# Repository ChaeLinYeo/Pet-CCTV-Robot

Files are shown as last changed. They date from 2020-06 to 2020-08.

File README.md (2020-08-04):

# Pet-CCTV-Robot
펫 자동 감지 CCTV
## Overview
  직장인들의 외출에 펫을 감시하기 위한 펫 CCTV, 하지만 기존 펫 CCTV는 사용자가 앱으로 직접 스트리밍 영상을 보면서 반려동물의 상황을 파악 해야하기 때문에 용무가 있어 외출을 한 사용자들에게는 스트리밍 영상을 통한 감시를 할 수 없는 상황이 대부분이다. 또한, 터치를 통해 구동되는 가전제품들이 증가함으로 반려동물의 사고 또한 빈번히 발생한다. 예로 반려동물 주인이 외출시 반려동물이 인덕션, 하이라이트 전자레인지 등을 건드려서 화재가 발생했다는 사건이 급증했다. ([화재사건기사내용](https://www.hankyung.com/life/article/201912041776Y)) 우리는 이에대해 기존의 제품이 구매자의 목적을 완벽하게 해소시켜주지 못한다는 점과 현재 사고들의 원인을 파악하여 사용자가 위험구역을 지정하고, 반려동물의 위치를 자동적으로 파악하여 기존 펫 CCTV의 부족한 점을 보완하고자한다.
 
## 세부 기능
- 사용자가 직접 본 기기 카메라에서 송출하는 화면을 통해 전면, 좌측, 우측 방향에 반려동물이 접근하면 안되는 구역을 설정을 할 수 있다.
- 본 기기는 인공지능을 통해 전면, 좌측, 우측 방향으로 반려동물의 위치를 파악한다.
- 반려동물이 사용자가 지정한 접근 금지 구역에 위치했을 때 기기는 음성을 송출하여 반려동물에게 제지를 하고, 사용자의 앱에 알림을 울린다. ([소리를 통해 반려동물을 제지할 수 있을까?](https://youtu.be/sFJ1QNv7OGw?t=42))

## 순차적 동작 개념 설명
1.	카메라에서 송출하고 있는 영상이 터치 스크린에 출력이 되고, 모터를 통해 움직이는 카메라의 각도(0도, 90도, 180도)별로 원하는 위험구역을 스크린에 터치한다.
2.	위험 구역 설정을 마무리하면, 카메라에서 촬영되고 있는 영상을 앱에 실시간으로 전송한다.
3.	5초 간격으로 모터를 돌려 카메라의 위치를 바꾼다. (이때 해당 카메라 각도로 설정한 위험구역을 불러온다.)
4.	고양이 / 강아지를 탐지한다.
5.	탐지한 고양이/ 강아지의 위치가 사용자가 설정한 위험구역 내에 위치할 경우 스피커로 음성 송출 및 사용자 앱에 알람을 송신한다.

## 사용재료
  라즈베리 파이3B+, 라즈베리 파이4, 라즈베리파이 카메라 모듈, USB허브, 서보모터, 마이크로 SD카드 32G, SD카드 리더기, 라즈베리파이 공식7인치 터치스크린

## 모델링
초기 모델 시안은 다음과 같다. 심미성 및 내부 하드웨어 위치를 고려하여 1번 구조를 택했으며, 이후에 하드웨어 크기를 고려하고, 3d 프린팅하기 쉬운 구조로 변형시켰다.
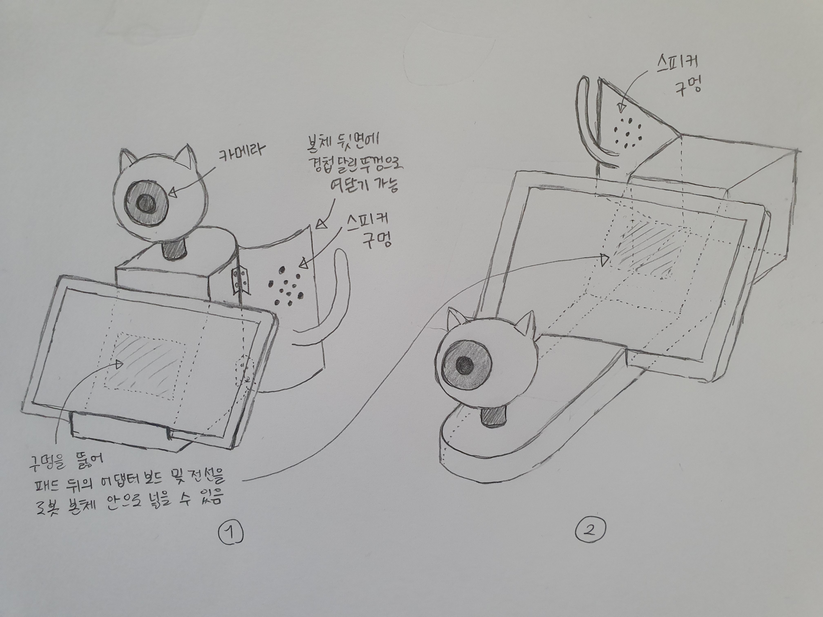
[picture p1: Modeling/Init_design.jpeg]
초기 시안

모델은 STL 파일로 첨부한다. 3D프린팅 편의를 위해 파트가 다음과 같이 분할되어 있다. 
```
.
├── cat_body_width_left.STL
├── cat_body_width_right.STL
├── real_cat_head_back.STL
├── real_cat_head_front.STL
└── real_cat_head_middle.STL
```
위의 파트들을 모두 합쳐 에셈블을 만들면 다음과 같다.
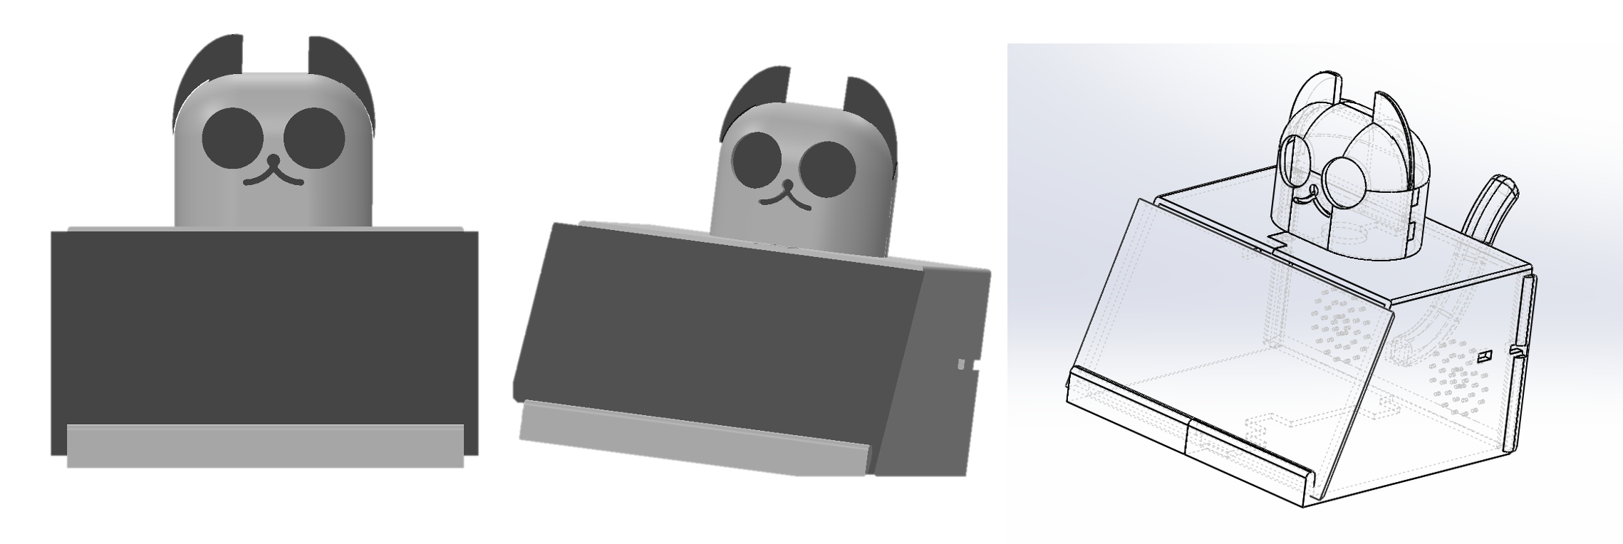
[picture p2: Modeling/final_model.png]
최종 모델


## 하드웨어 세부 구성
```
.
├── Google Edge TPU coprocessor : 인공지능 영상처리 가속화
├── raspberry pi 3 B+: 사용자에게 영상을 스트리밍 해줄 보드 
├── raspberry pi 4: 애완동물을 인식하여 위험구역을 탐지할 보드
├── arduino UNO: 모터를 제어할 보드
├── HS-311 servo motor: 카메라를 돌려줄 모터
├── SONY pi camera x 2: 카메라(하나는 애완동물 인식, 하나는 스트리밍용)
├── raspberry pi touch screen 7 inch: 사용자가 상호작용할 터치디스플레이
└── USB port speaker: 음성을 출력할 스피커
```

## 반려동물 감지 (detection)
파이카메라로 받은 영상을 Tensorflow-Lite와 OpenCV, Google의  sample TFLite model를 이용하여 고양이, 강아지, 새 등의 애완동물을 인공지능으로 학습하여 인식 가능하게 만들었다. 파이카메라로 영상을 받으면, 처음에 터치스크린을 터치하여 화면 상의 위험 구역을 선정한다. 그러면 화면 상에 고양이, 강아지 등 반려동물이 보이면 인공지능이 인식을 하고, 사용자가 선정한 위험 구역 범위에 인식된 반려동물의 좌표값이 들어오면 “Cat/Dog is danger!”라는 문구를 띄운다. 영상처리에서는 FPS를 개선하기 위해 TPU Accelerator를 사용하였으며, raspberry pi 3 B 에서 raspberry pi 4로 새로 교체하여 기존의 파이카메라로 영상처리를 할때 약 1~2 FPS였던 것을 약 30~40 FPS정도까지 끌어올려 부드러운 영상이 나오도록 했다. 
파일 실행 방법은 다음과 같다.
```
source tflite1-env/bin/activate
python3 TFLite_detection_webcam.py --modeldir=Sample_TFLite_model --edgetpu
```
## 애플리케이션
앱으로도 카메라의 영상이 스트리밍 될 수 있도록 하기 위해 UV4L을 사용하여 웹에서 영상이 스트리밍 될 수 있도록 하고, 안드로이드 스튜디오에서 웹에서 스트리밍되는 영상을 WebView를 통해 볼 수 있도록 했다. 스트리밍 하는 영상의 width, height, brightness, contrast, saturation, rgb balance, sharpness, rotate, jpeg quality, frame rate, horizontal mirror, vertical mirror, video denoise, image stabilization 등등 다양한 설정값을 변경하여 영상 스트리밍을 앱으로 받아볼 수 있다. 라즈베리 파이에서 인공지능으로 고양이, 강아지를 인식하여 사용자가 지정한 위험구역에 들어오면 앱으로 푸쉬알람을 보낸다. 사용자가 이름과 email 정보를 입력하면 반려동물이 위험구역에 접근했을 때 앱으로 알림이 가는 서비스를 구독할 수 있다. 구독자의 정보는 파이어베이스 데이터베이스에 실시간으로 반영되고, 구독 해지 시 자동으로 데이터베이스에서 정보를 삭제한다. 파이어베이스에서 사용자들의 정보와 사용량, 동시 연결 수, 클라우드 메시징(푸쉬알람)이 사용자에게 몇번 전송되고, 수신되고, 노출되고, 열렸는지를 실시간으로 모니터링할 수 있다. 또한 여러 대의 스마트폰 디바이스에서 실시간 스트리밍을 볼 수 있고, 푸쉬알람을 받을 수 있다.

## 시연 영상
Video Label (https://youtu.be/2APS1OUAQUU)

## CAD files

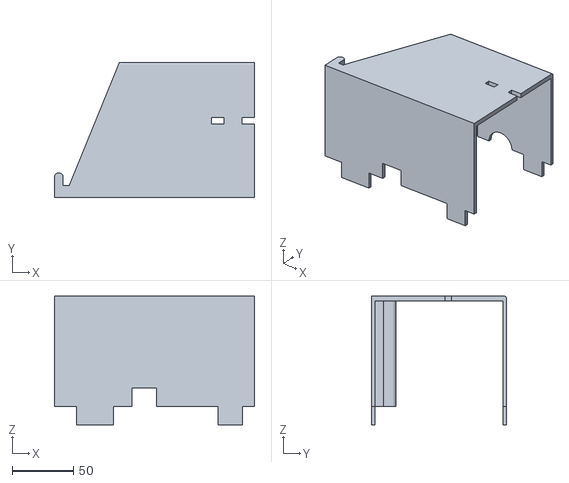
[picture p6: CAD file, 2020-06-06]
Modeling/cat_body_width_right.STL
162.8 x 110.0 x 105.0

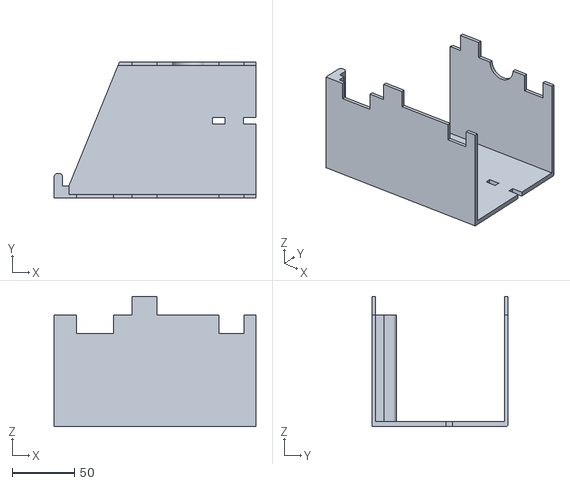
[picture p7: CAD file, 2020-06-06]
Modeling/cat_body_width_left.STL
162.8 x 110.0 x 105.0

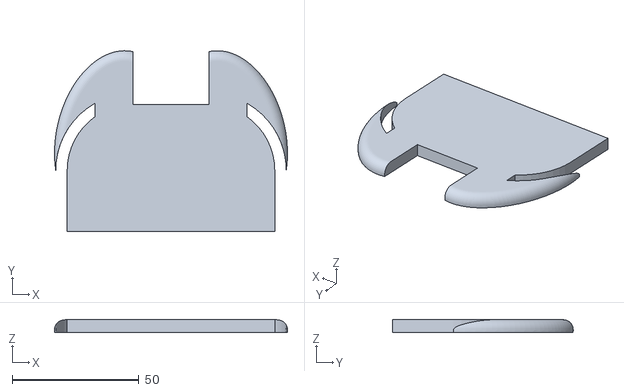
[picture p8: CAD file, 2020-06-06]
Modeling/real_cat_head_middle.STL
92.0 x 71.3 x 5.00

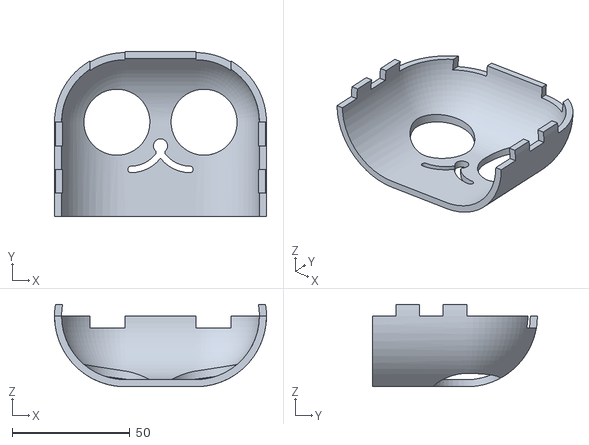
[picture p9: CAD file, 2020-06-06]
Modeling/real_cat_head_front.STL
90.0 x 70.0 x 35.0

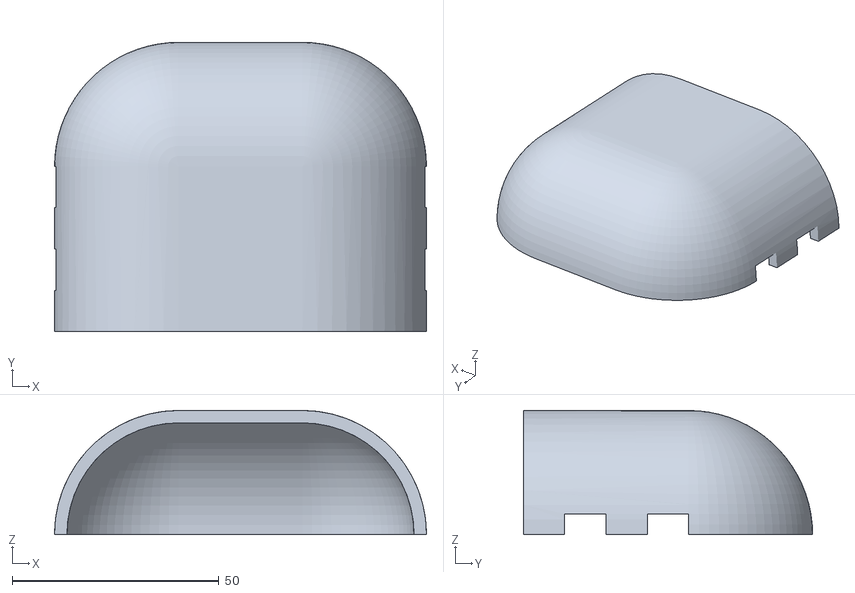
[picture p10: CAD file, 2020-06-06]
Modeling/real_cat_head_back.STL
90.0 x 70.0 x 30.0

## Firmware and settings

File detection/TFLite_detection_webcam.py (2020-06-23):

######## Webcam Object Detection Using Tensorflow-trained Classifier #########
#
# Author: Evan Juras
# Date: 10/27/19
# Description: 
# This program uses a TensorFlow Lite model to perform object detection on a live webcam
# feed. It draws boxes and scores around the objects of interest in each frame from the
# webcam. To improve FPS, the webcam object runs in a separate thread from the main program.
# This script will work with either a Picamera or regular USB webcam.
#
# This code is based off the TensorFlow Lite image classification example at:
# https://github.com/tensorflow/tensorflow/blob/master/tensorflow/lite/examples/python/label_image.py
#
# I added my own method of drawing boxes and labels using OpenCV.

# Import packages
import os
import argparse
import cv2
import numpy as np
import sys
import time
from threading import Thread
import importlib.util
import serial

# Define VideoStream class to handle streaming of video from webcam in separate processing thread
# Source - Adrian Rosebrock, PyImageSearch: https://www.pyimagesearch.com/2015/12/28/increasing-raspberry-pi-fps-with-python-and-opencv/
class VideoStream:
    """Camera object that controls video streaming from the Picamera"""
    def __init__(self,resolution=(640,480),framerate=30):
        # Initialize the PiCamera and the camera image stream
        self.stream = cv2.VideoCapture(0)
        ret = self.stream.set(cv2.CAP_PROP_FOURCC, cv2.VideoWriter_fourcc(*'MJPG'))
        ret = self.stream.set(3,resolution[0])
        ret = self.stream.set(4,resolution[1])
            
        # Read first frame from the stream
        (self.grabbed, self.frame) = self.stream.read()

	# Variable to control when the camera is stopped
        self.stopped = False

    def start(self):
	# Start the thread that reads frames from the video stream
        Thread(target=self.update,args=()).start()
        return self

    def update(self):
        # Keep looping indefinitely until the thread is stopped
        while True:
            # If the camera is stopped, stop the thread
            if self.stopped:
                # Close camera resources
                self.stream.release()
                return

            # Otherwise, grab the next frame from the stream
            (self.grabbed, self.frame) = self.stream.read()

    def read(self):
	# Return the most recent frame
        return self.frame

    def stop(self):
	# Indicate that the camera and thread should be stopped
        self.stopped = True
# set mouse event
mouse_event_types = { 0:"EVENT_MOUSEMOVE", 1:"EVENT_LBUTTONDOWN", 2:"EVENT_RBUTTONDOWN", 3:"EVENT_MBUTTONDOWN",
                 4:"EVENT_LBUTTONUP", 5:"EVENT_RBUTTONUP", 6:"EVENT_MBUTTONUP",
                 7:"EVENT_LBUTTONDBLCLK", 8:"EVENT_RBUTTONDBLCLK", 9:"EVENT_MBUTTONDBLCLK",
                 10:"EVENT_MOUSEWHEEL", 11:"EVENT_MOUSEHWHEEL"}

mouse_event_flags = { 0:"None", 1:"EVENT_FLAG_LBUTTON", 2:"EVENT_FLAG_RBUTTON", 4:"EVENT_FLAG_MBUTTON",
                8:"EVENT_FLAG_CTRLKEY", 9:"EVENT_FLAG_CTRLKEY + EVENT_FLAG_LBUTTON",
                10:"EVENT_FLAG_CTRLKEY + EVENT_FLAG_RBUTTON", 11:"EVENT_FLAG_CTRLKEY + EVENT_FLAG_MBUTTON",

                16:"EVENT_FLAG_SHIFTKEY", 17:"EVENT_FLAG_SHIFTKEY + EVENT_FLAG_LBUTTON",
                18:"EVENT_FLAG_SHIFTLKEY + EVENT_FLAG_RBUTTON", 19:"EVENT_FLAG_SHIFTKEY + EVENT_FLAG_MBUTTON",

                32:"EVENT_FLAG_ALTKEY", 33:"EVENT_FLAG_ALTKEY + EVENT_FLAG_LBUTTON",
                34:"EVENT_FLAG_ALTKEY + EVENT_FLAG_RBUTTON", 35:"EVENT_FLAG_ALTKEY + EVENT_FLAG_MBUTTON"}

ser = serial.Serial('/dev/ttyAMA0',9600);

# Define and parse input arguments
parser = argparse.ArgumentParser()
parser.add_argument('--modeldir', help='Folder the .tflite file is located in',
                    required=True)
parser.add_argument('--graph', help='Name of the .tflite file, if different than detect.tflite',
                    default='detect.tflite')
parser.add_argument('--labels', help='Name of the labelmap file, if different than labelmap.txt',
                    default='labelmap.txt')
parser.add_argument('--threshold', help='Minimum confidence threshold for displaying detected objects',
                    default=0.5)
parser.add_argument('--resolution', help='Desired webcam resolution in WxH. If the webcam does not support the resolution entered, errors may occur.',
                    default='640x480')
parser.add_argument('--edgetpu', help='Use Coral Edge TPU Accelerator to speed up detection',
                    action='store_true')

args = parser.parse_args()

MODEL_NAME = args.modeldir
GRAPH_NAME = args.graph
LABELMAP_NAME = args.labels
min_conf_threshold = float(args.threshold)
resW, resH = args.resolution.split('x')
imW, imH = int(resW), int(resH)
use_TPU = args.edgetpu

# Import TensorFlow libraries
# If tflite_runtime is installed, import interpreter from tflite_runtime, else import from regular tensorflow
# If using Coral Edge TPU, import the load_delegate library
pkg = importlib.util.find_spec('tflite_runtime')
if pkg:
    from tflite_runtime.interpreter import Interpreter
    if use_TPU:
        from tflite_runtime.interpreter import load_delegate
else:
    from tensorflow.lite.python.interpreter import Interpreter
    if use_TPU:
        from tensorflow.lite.python.interpreter import load_delegate

# If using Edge TPU, assign filename for Edge TPU model
if use_TPU:
    # If user has specified the name of the .tflite file, use that name, otherwise use default 'edgetpu.tflite'
    if (GRAPH_NAME == 'detect.tflite'):
        GRAPH_NAME = 'edgetpu.tflite'       

# Get path to current working directory
CWD_PATH = os.getcwd()

# Path to .tflite file, which contains the model that is used for object detection
PATH_TO_CKPT = os.path.join(CWD_PATH,MODEL_NAME,GRAPH_NAME)

# Path to label map file
PATH_TO_LABELS = os.path.join(CWD_PATH,MODEL_NAME,LABELMAP_NAME)

# Load the label map
with open(PATH_TO_LABELS, 'r') as f:
    labels = [line.strip() for line in f.readlines()]

# Have to do a weird fix for label map if using the COCO "starter model" from
# https://www.tensorflow.org/lite/models/object_detection/overview
# First label is '???', which has to be removed.
if labels[0] == '???':
    del(labels[0])

# Load the Tensorflow Lite model.
# If using Edge TPU, use special load_delegate argument
if use_TPU:
    interpreter = Interpreter(model_path=PATH_TO_CKPT,
                              experimental_delegates=[load_delegate('libedgetpu.so.1.0')])
    print(PATH_TO_CKPT)
else:
    interpreter = Interpreter(model_path=PATH_TO_CKPT)

interpreter.allocate_tensors()

# Get model details
input_details = interpreter.get_input_details()
output_details = interpreter.get_output_details()
height = input_details[0]['shape'][1]
width = input_details[0]['shape'][2]

floating_model = (input_details[0]['dtype'] == np.float32)

input_mean = 127.5
input_std = 127.5

# Initialize frame rate calculation
frame_rate_calc = 1
freq = cv2.getTickFrequency()

# Initialize video stream
videostream = VideoStream(resolution=(imW,imH),framerate=30).start()
time.sleep(1)
# click event

danger_done = 0
set_danger_box = []
def mouse_callback(event, x, y, flags, param):
    global danger_done, set_danger_box
    if event == 1 : 
        print( '{0} ,{1}'.format(x,y))
        danger_done +=1
        set_danger_box.append((x,y))

while True:
    
    danger_frame = videostream.read()
    cv2.imshow('set_danger', danger_frame)
    cv2.setMouseCallback('set_danger', mouse_callback)
    if(danger_done > 1):
        break
    k = cv2.waitKey(1)
    if k == 27:
        break
cv2.destroyAllWindows()
#for frame1 in camera.capture_continuous(rawCapture, format="bgr",use_video_port=True):
count = 0
while True:
    count += 1
    if( count > 30 ) :
        print('turn!')
        count = 0 # initialize
        #ser.write(bytes('1',encoding='ascii'))# '1' is patroll, '2' is stop
        print('turn done!')
        #To Do

    # Start timer (for calculating frame rate)
    t1 = cv2.getTickCount()

    # Grab frame from video stream
    frame1 = videostream.read()

    # Acquire frame and resize to expected shape [1xHxWx3]
    frame = frame1.copy()
    frame_rgb = cv2.cvtColor(frame, cv2.COLOR_BGR2RGB)
    frame_resized = cv2.resize(frame_rgb, (width, height))
    input_data = np.expand_dims(frame_resized, axis=0)

    # Normalize pixel values if using a floating model (i.e. if model is non-quantized)
    if floating_model:
        input_data = (np.float32(input_data) - input_mean) / input_std

    # Perform the actual detection by running the model with the image as input
    interpreter.set_tensor(input_details[0]['index'],input_data)
    interpreter.invoke()

    # Retrieve detection results
    boxes = interpreter.get_tensor(output_details[0]['index'])[0] # Bounding box coordinates of detected objects
    classes = interpreter.get_tensor(output_details[1]['index'])[0] # Class index of detected objects
    scores = interpreter.get_tensor(output_details[2]['index'])[0] # Confidence of detected objects
    #num = interpreter.get_tensor(output_details[3]['index'])[0]  # Total number of detected objects (inaccurate and not needed)

    # Loop over all detections and draw detection box if confidence is above minimum threshold
    for i in range(len(scores)):
        if ((scores[i] > min_conf_threshold) and (scores[i] <= 1.0)):
            if(labels[int(classes[i])] == 'cat' or labels[int(classes[i])] == 'dog'):

                # Get bounding box coordinates and draw box
                # Interpreter can return coordinates that are outside of image dimensions, need to force them to be within image using max() and min()
                ymin = int(max(1,(boxes[i][0] * imH)))
                xmin = int(max(1,(boxes[i][1] * imW)))
                ymax = int(min(imH,(boxes[i][2] * imH)))
                xmax = int(min(imW,(boxes[i][3] * imW)))
            
                cv2.rectangle(frame, (xmin,ymin), (xmax,ymax), (10, 255, 0), 2)

                # Draw label
                object_name = labels[int(classes[i])] # Look up object name from "labels" array using class index
                label = '%s: %d%%' % (object_name, int(scores[i]*100)) # Example: 'person: 72%'
                labelSize, baseLine = cv2.getTextSize(label, cv2.FONT_HERSHEY_SIMPLEX, 0.7, 2) # Get font size
                label_ymin = max(ymin, labelSize[1] + 10) # Make sure not to draw label too close to top of window
                cv2.rectangle(frame, (xmin, label_ymin-labelSize[1]-10), (xmin+labelSize[0], label_ymin+baseLine-10), (255, 255, 255), cv2.FILLED) # Draw white box to put label text in
                cv2.putText(frame, label, (xmin, label_ymin-7), cv2.FONT_HERSHEY_SIMPLEX, 0.7, (0, 0, 0), 2) # Draw label text
                #print('minx,y',xmin,ymin)
                #print('maxx,y',xmax,ymax)
                for i in range(0,len(set_danger_box),2):
                    if((xmin < set_danger_box[i][0] < xmax and ymin < set_danger_box[i][1] < ymax) or ((xmin < set_danger_box[i+1][0] < xmax and ymin < set_danger_box[i+1][1] < ymax))):
                        print("Cat/Dog is Danger!")
                    
    # Draw framerate in corner of frame
    cv2.putText(frame,'FPS: {0:.2f}'.format(frame_rate_calc),(30,50),cv2.FONT_HERSHEY_SIMPLEX,1,(255,255,0),2,cv2.LINE_AA)

    # All the results have been drawn on the frame, so it's time to display it.
    cv2.imshow('Object detector', frame)

    # Calculate framerate
    t2 = cv2.getTickCount()
    time1 = (t2-t1)/freq
    frame_rate_calc= 1/time1

    # Press 'q' to quit
    if cv2.waitKey(1) == ord('q'):
        break

# Clean up
cv2.destroyAllWindows()
videostream.stop()

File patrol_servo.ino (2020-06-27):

#include <Servo.h>

Servo sv;

long input = -1;
int direct = -1;
long angle = 90;
long n_angle = 90;
long spd = 2;
int index = 0;
int patrol_index = 0;
long d = 0;

long angle_list[] = {0,180,90};
long angle_list2[] = {0,90,180};

void setAngle();
void moveServo(long);

void setup() {
  sv.attach(3);//3번핀에 PWM연결
  sv.write(angle);
  Serial.begin(115200);
}

void loop() {
  
  d = n_angle - angle; //도착 각도와 현재 각도 비교
  if(d < 1 - spd){
    n_angle += spd;
  }else if(d > spd -1){//1도씩 움직이며 부드럽게 움직이고 속도 제어할수 있게함
    n_angle -= spd;
  }

  moveServo(n_angle); //모터 움직이기

  Serial.print("input :");
  Serial.print(input);
  Serial.print("  angle: ");
  Serial.print(angle);
  Serial.print("  n_angle: ");
  Serial.print(n_angle);
  Serial.print("  d: ");
  Serial.print(d);
  Serial.println("");
  delay(10);
}

void serialEvent(){
  int _input = Serial.parseInt();
  if(_input != -1){
    input = _input;
    setAngle();
  }
}

void setAngle(){
  switch(input){ //입력에 따라 반응
    case -1:
      Serial.print("input is not exist");
      break;

    case 0://위험구역 설정 0,90,180 에서 멈춰서 다시 '0'들어올때 각도 증가
      angle = angle_list[index];
      index++;
      if(index > 2) index = 0; //2는 angle_list의 길이 -1
      break;

    case 1://고개 돌리기
      Serial.print(input);
      angle = angle_list2[patrol_index];

      patrol_index += direct;
      if(patrol_index > 2){
        patrol_index = 1;
        direct *= -1;
      }else if(patrol_index < 0){
        patrol_index = 1;
        direct *= -1;
      }      
      break;

    case 2://정지
      Serial.print(input);
      angle = n_angle;
      delay(3000);
      break;

    case 3: //처음
      angle = 90;
      break;
      
    default:
      Serial.print("unknown input: ");
      Serial.print(input);
      break;      
  }
}

void moveServo(long angle){
  sv.write(angle);
}

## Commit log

2020-06-06 모델링 리드미 추가(더 추가 에정)
2020-06-06 사진 첨부
2020-06-23 안드로이드 앱 업로드
2020-06-23 서보모터 움직이기
